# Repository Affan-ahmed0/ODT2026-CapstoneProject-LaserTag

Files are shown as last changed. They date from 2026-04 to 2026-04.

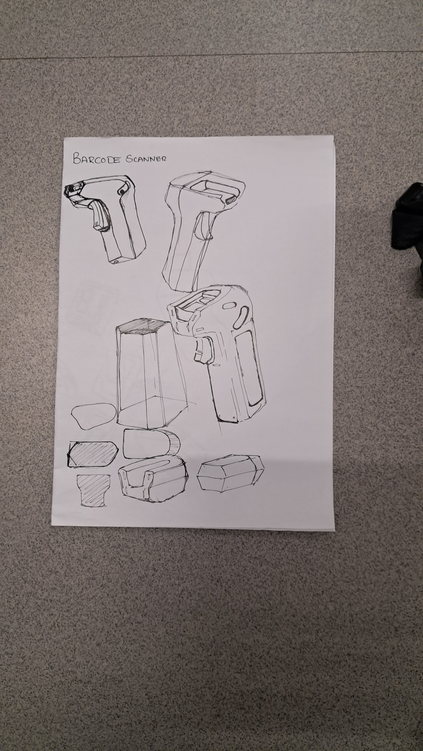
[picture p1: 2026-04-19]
Mechanical Details/Ideation/Final Form.jpg

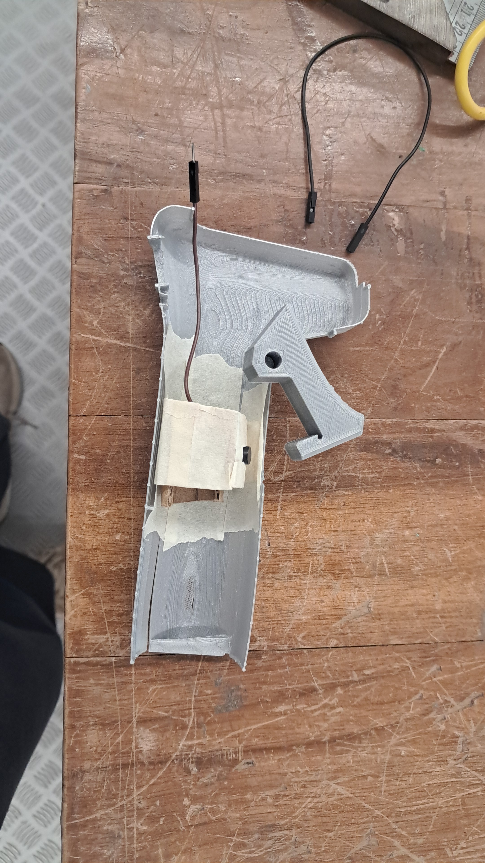
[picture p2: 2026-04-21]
Media/Final/IMG-20260420-WA0010.jpeg

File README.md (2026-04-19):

# **Project Title**

# 🔦⚡Laser Tag⚡🔦

**📌 Project Overview**

A Multiplayer Game of ***Laser Tag***. Where players shoot each other with a gun that shoots lasers to kill the other player. It makes use of the **ESP NOW** Protocol to make a Peer-to-peer architecture, making a gaming platform between that runs between the network of Gun Modules. 

The gun uses IR signals as the communication between the devices when one player is hit. We align the IR Emitter with the Laser module to ensure the visual point of impact (through the Laser) and the digital signal area is aligned. 

**📂 Repository Structure**

1. Electronics Details

2. Mechanical Details

3. Software Details

4. Project Documents

5. Media

**⚙️ How to Navigate This Repository**

Electronics Details → Circuit, components justification

Mechanical Details → Sketches, CAD, and fabrication

Software Details → Code, logic, and implementation

Project Documents → Design thinking, planning, testing

Media → Weekly progress and final output

**👥 Team Members**  

Anushka Kulkarni  

Affan Ahmed

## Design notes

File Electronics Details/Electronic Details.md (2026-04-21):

# Components Used:

**Laser Dot Diode Module:** Acts as visual aid for player to know where they are shooting  

**ESP32:** Used for computing the signals, giving outputs and Wireless communication between ESP32's  

**OLED Display:** Displays information to the Player.  

**Active Buzzer:** Gives audible feedback to the player when hit registered and game ends.  

**3 Stage Slider Switch:** Controls the power to the ESP32  

**Push Button (Trigger):** Fires Laser and IR Emmiter when pressed  

**Battery:** Powers the ESP32

# Components used & Purpose

### Project Components Overview

| Component | Purpose | Justification of Use |
| :--- | :--- | :--- |
| **ESP32 Microcontroller** | Central processing and logic unit. | Processing of signals from sensors and built-in Wi-Fi/Bluetooth for future scoring sync. |
| **Laser Dot Diode (650nm)** | Visual aiming reference. | Provides a clear, visible point of impact for the player without interfering with the IR data stream. |
| **0.96" OLED Display [PIN 21 (SLC) PIN 21 (SDA)]** | Real-time Head-Up Display (HUD). | Provides essential game telemetry (health, ammo, team) in a compact, low-power I2C form factor. |
| **Active Buzzer** | Audio feedback system. | Low-latency audible alerts for "hits" and "firing," essential for situational awareness during play. |
| **3-Stage Slide Switch** | Power and state control. | Switches between Connecting mode to connect between the ESP's in a room and Play mode |
| **Push Button (Trigger)** | Input for firing action. | Provides tactile feedback for the user and give input to the ESP32 |
| **4x AA Battery Pack** | Portable power supply. | Readily available and provides a stable 6V input to the ESP32’s voltage regulator for long-duration play. |

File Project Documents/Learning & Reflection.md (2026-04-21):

## 📝 Project Reflection

This project served as an intensive exploration into the physical and technical constraints of embedded systems. Moving from a conceptual schematic to a handheld, 17cm prototype required navigating a series of cascading engineering challenges. The core of the difficulty lay in the spatial reconciliation between the electronic architecture and the mechanical housing.

The initial planning phase was rigorous, involving detailed CAD modeling in Fusion 360 to ensure the ESP32, OLED, and battery pack would physically coexist within the shell. However, the transition to physical assembly revealed the true complexity of the design. The system relied on an overwhelming number of discrete connections, including I2C lines for the HUD, signal lines for the laser and IR emitter, and the high-speed sampling wire for the raw IR receiver. Each component required precise routing through the narrow internal chassis.

Minor issues with soldering joints and wire fatigue necessitated constant continuity checking, as even a single loose ground would compromise the NEC protocol’s timing. Despite exhaustive planning to join the internal mounting plates with the outer shell, the sheer volume of 22AWG wiring eventually exceeded the internal volume of the 3D-printed gun casing. This density of connections ultimately led to the failure of integrating the circuit inside the gun shell. This struggle highlighted a vital lesson in product design: the "logical" space on a circuit board and the "physical" volume of a housing are two vastly different realities that demand significant margin for error.

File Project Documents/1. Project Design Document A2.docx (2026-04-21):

# Project Design Document

### 1. Design Intent

- The Experience: A high-precision, "sniper-style" competitive game. Unlike commercial IR laser tag that "sprays" light, this is about steady hands and accurate aiming. It creates a high-stakes, "one-shot-matters" atmosphere.
- The Audience: DIY makers, hobbyists, or friends looking for a low-cost, high-tech backyard game.
- The Problem: Professional laser tag equipment is expensive and often relies on "invisible" beams. This project uses visible lasers for immediate feedback and utilizes common, affordable components (LDRs/OLEDs) to make high-tech gaming accessible.

### 2. Inspiration & References

- How Real Laser Tag Works (https://www.youtube.com/watch?v=piLtAyrR_mE)

### 3. User Journey

1. The Start: The player dons the helmet and grips the gun. They flip a toggle switch. The OLED screen splashes a "SYSTEM READY" logo, the neopixel and settles on "LIVES: 03," strip turns on.
2. The Hunt: The user creeps through a low-light environment. They see their opponent and squeeze the Trigger. A red beam streaks across the room.
3. The Interaction: The player's beam hits one of the LDR sensors on the opponent's helmet.
4. The Response: * Opponent Side: Their helmet MCU detects the sudden drop in LDR resistance. The OLED flashes "HIT!" and the life count drops to "02." The Neopixel strip flashes red for 3 seconds to indicate a hit.
  - Attacker Side: The attacker sees the opponent's flash, confirming a successful strike.
5. Cooldown: There is a cooldown of 3 seconds after every 15 shots. There is also a 3-second invulnerable state for player who has just been shot.
6. The End: Once a player's OLED hits "00," the screen displays "GAME OVER – DEFEATED."

### 4. Success Criteria

- Functional: Hit detection must occur in <100ms to feel "real-time." The laser must stay active only as long as the trigger is held (or for a set pulse duration).
- User Experience: The OLED must be high-contrast enough to read at a glance while moving. The helmet must be light enough to be comfortable for 15 minutes of play.
- Reliability: The system must distinguish between a laser hit and ambient room light (achieved through software thresholding).

### 5. System Overview

The system is a Distributed Wearable Network. Each "Player Unit" is a closed loop.

- The Brain (MCU): An Arduino Nano or ESP32 mounted on the helmet.
- The Peripheral (Gun): Connected via a "leash" wire, containing the laser diode and the trigger button.
- The Sensory Array (Helmet): 3–4 LDRs wired in parallel or to individual analog pins to provide 360° detection coverage.
- The Interface (OLED): A 0.96" I2C screen providing health and ammo status.

### 6. High-Level Block Diagram

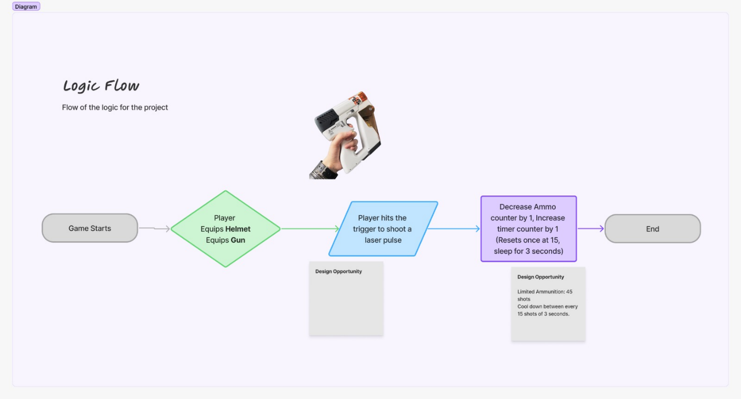
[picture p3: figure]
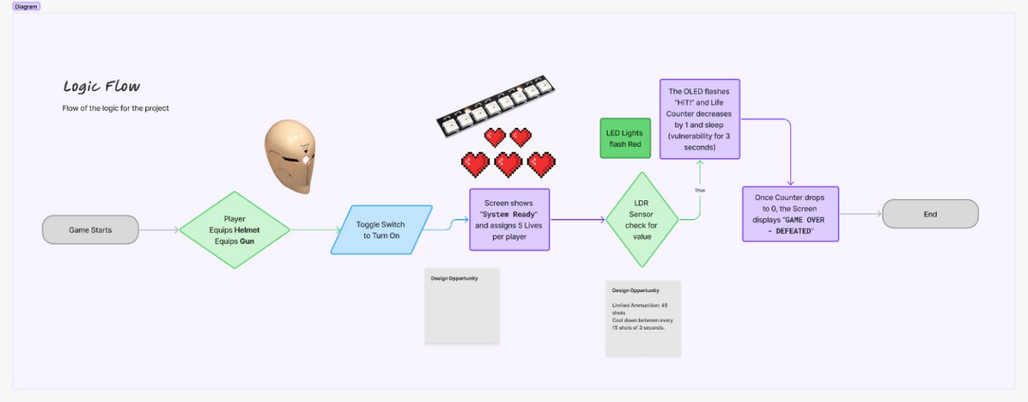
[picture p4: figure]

### 7. Input / Output Mapping

Input | Process | Output
Trigger Button (Digital Input) | Check if player has "lives" left. If yes, send power to Laser Diode. | Laser Beam (Red light emission)
LDR Sensor (Analog Input) | Compare light level to a pre-set "Threshold." If change is >40%, trigger "Hit Logic." | OLED Update (Lives -1)
LDR Sensor (Analog Input) | If "Hit Logic" is active, start a 2-second "Invincibility Timer." | Status LED (Red flashing)
Software Timer | Monitor time since last shot to prevent "Machine Gun" spamming. | OLED Animation ("Reloading...")

### 8. Sketches & Concepts

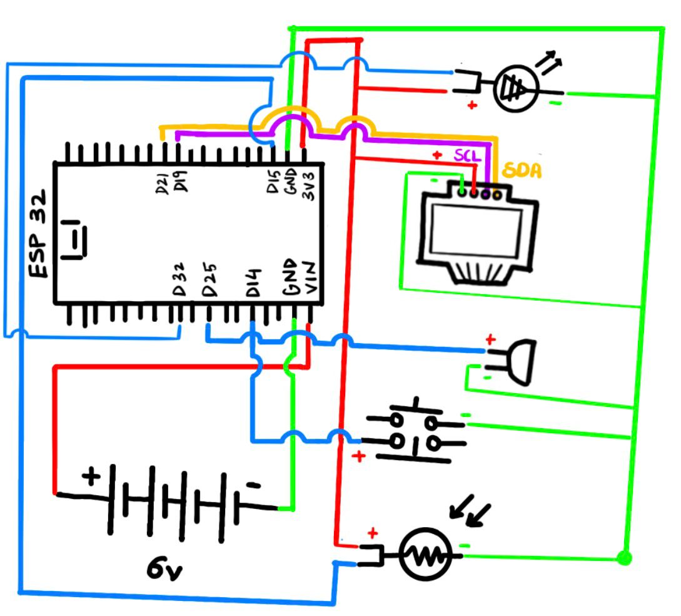
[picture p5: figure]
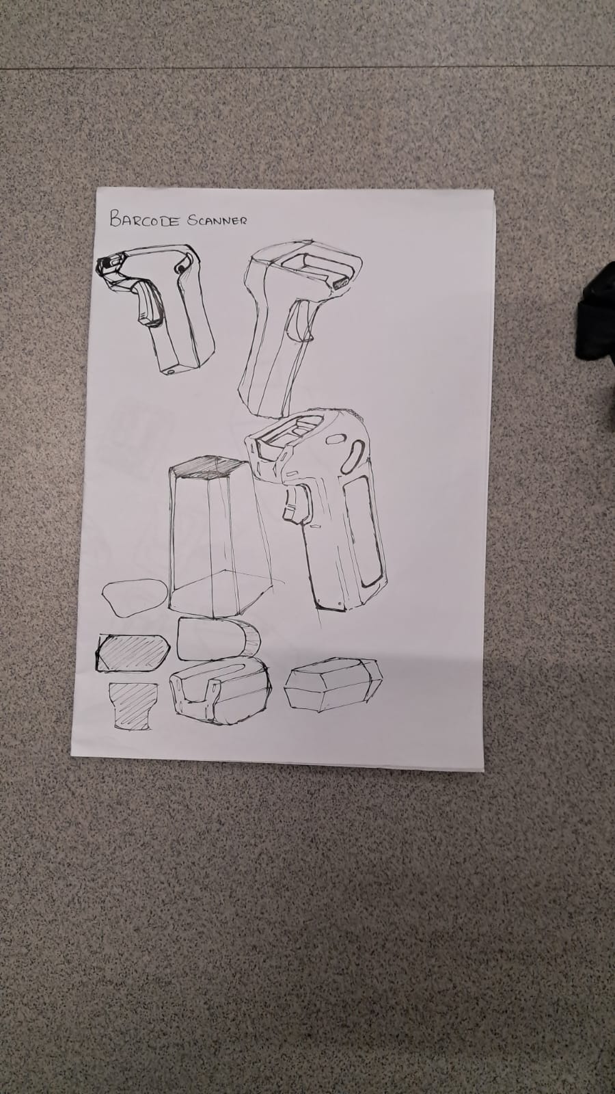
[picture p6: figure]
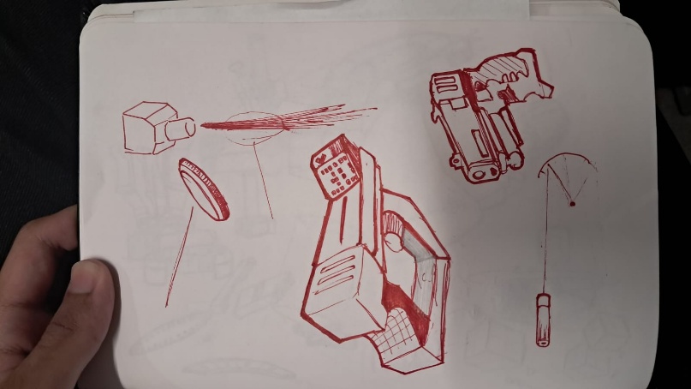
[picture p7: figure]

### 9. Final System Architecture (Labelled)

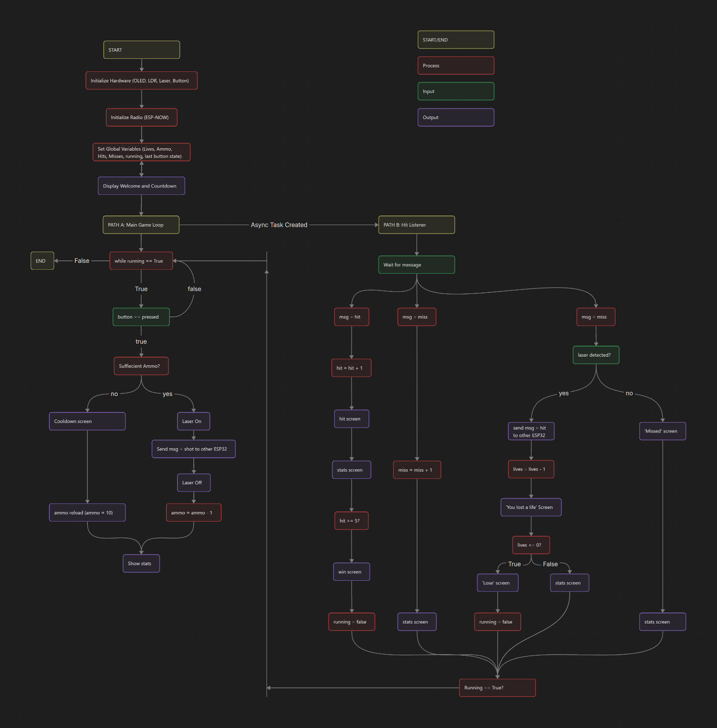
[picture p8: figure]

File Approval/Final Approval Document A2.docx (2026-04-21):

ODT Summative 2

Idea Brief:

1. Project Overview

Photon Strike is a wearable electronic game consisting of a hand-held laser emitter (The Gun) and a head-mounted receiver (The Helmet). The goal is to "tag" opponents by hitting their helmet sensors with a laser beam. Each helmet tracks its own health or hit count in real-time, displaying the data on an integrated OLED screen.

2. Hardware Architecture

The Gun (Emitter)

- Laser Pointer
- Trigger
- Feedback: A buzzer for "pew-pew" sounds

The Helmet (Receiver)

- ESP32: To process sensor data and drive the display.
- LDR Sensor
- Display: OLED Screen (128x64) mounted on the brim or side to show "Lives Remaining" or "Hit Count."
- Indicator: A bright LED that flashes when the player is hit.

3. Core Game Mechanics

1. The Shot: When the trigger is pulled, the laser emits a brief pulse.
2. The Detection: The LDRs on the helmet constantly monitor ambient light levels. When a laser hits an LDR, the resistance drops sharply and suddenly.
3. The Logic: The microcontroller detects this "voltage spike." To prevent sunlight or room lights from triggering a hit, the code must look for a specific threshold of change over a very short duration.
4. Feedback Loop: The OLED updates the score (e.g., "HITS: 04").
  - The helmet buzzer sounds for 1 second.
  - The helmet goes into a brief "invincibility window" (2 seconds) to prevent multi-hit spamming.

Basic Idea Sketch

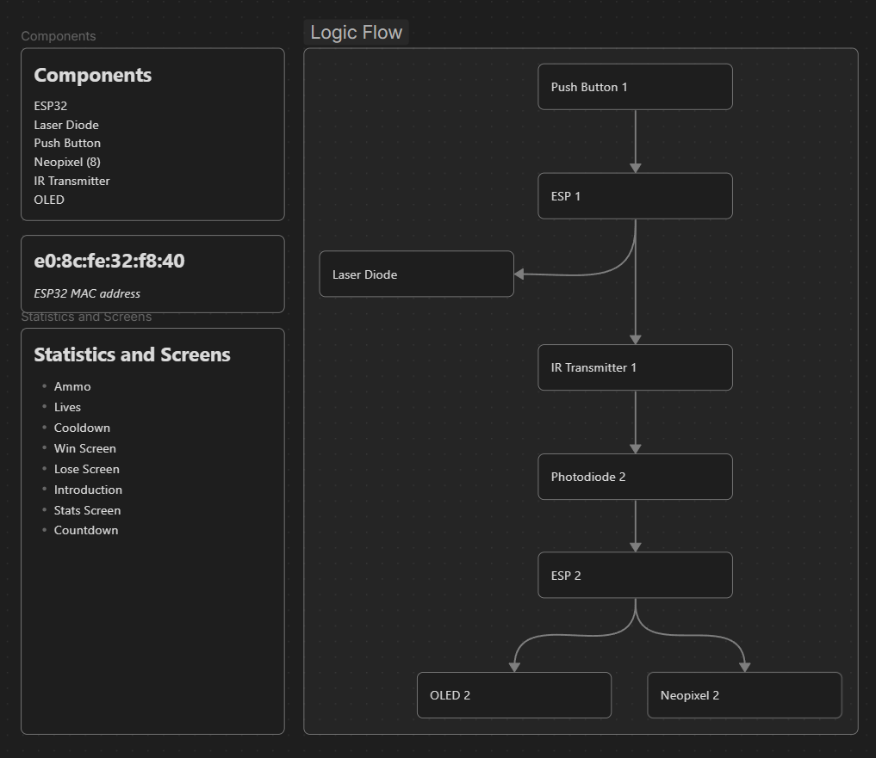
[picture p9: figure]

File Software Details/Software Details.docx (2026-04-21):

# Software Documentation

### 1. Software Overview

What does the software do?

- The software manages a real-time, wireless laser tag duel system for two players. It coordinates the hardware components (Laser, LDR, Button, and OLED Display) and handles peer-to-peer communication between two ESP32 microcontrollers using the ESP-NOW protocol.

Key features include:

- Asynchronous Dual-Track Processing: The software utilizes asyncio to simultaneously monitor the trigger/laser firing logic (Attacker track) and an background radio listener (Victim track).
- Response-Confirmation Handshake: Unlike simple one-way infrared systems, this software uses a "handshake" protocol. When a shot is fired, the attacker notifies the victim via radio; the victim immediately checks their sensor and broadcasts a confirmation ("Hit" or "Miss") back to the attacker to update scores in real-time.
- State Management: The system tracks and displays live game statistics, including health (lives), ammunition, successful hits, and misses, while enforcing game rules like firing cooldowns and win/loss conditions.

Platforms Used

- MicroPython (v1.20+): The primary programming language used for the firmware, chosen for its efficient handling of hardware-level interrupts and high-level asynchronous programming.
- asyncio Library: Used to manage non-blocking tasks, ensuring the gun remains responsive to being hit while the player is busy firing or navigating menus.
- aioespnow: A specialized MicroPython wrapper for ESP-NOW, a connectionless Wi-Fi communication protocol that provides low-latency, long-range data transmission between the devices.
- SSD1306 OLED Driver: A frame-buffer based driver used to render the graphical user interface (GUI) and real-time statistics on the I2C display.
- Thonny IDE: Used for script development, debugging, and flashing the modular file system (main.py, comms.py, screen.py) to the ESP32 units.

### 2. System Logic

1. Game Initialization
- Boot: The ESP32 initializes the Wi-Fi radio (ESP-NOW), I2C Display, and GPIO pins (Laser, Button, Sensor).
- Setup: The screen displays a welcome sequence and countdown while the background "Listener" task starts.
- Standby: The system enters a loop, waiting for either a trigger pull (Attacker) or a radio signal (Victim).
2. The Attacker Flow (Shooting)
- Trigger: User presses the physical button.
- Action: If ammo is available, the ESP32 turns on the Laser and simultaneously broadcasts a "Shot" signal via ESP-NOW.
- Wait: The Attacker pauses for the victim’s response (handled by the background listener).
- Result:
- If a "Hit" signal is received back: The score (hits) increases and a "Victory" animation plays.
- If a "Miss" signal is received back: The "Misses" count increases.
3. The Victim Flow (Being Shot At)
  a. Radio Catch: The background listener receives a "Shot" signal from the opponent.
  b. Sensor Check: The ESP32 immediately reads the LDR (Light Dependent Resistor) value.
4. Detection:
  a. If Laser detected: The ESP32 subtracts a life, displays a "Hit" animation, and sends a "Hit" confirmation back to the attacker.
  b. If Laser NOT detected: The ESP32 sends a "Miss" confirmation back to the attacker.
5. End of Game
  - Victory/Defeat: The system constantly checks if lives == 0 or hits == 5.
  - Kill-Switch: Once a condition is met, the global running flag is set to False.
  - Termination: Both the main loop and background listener stop, and the final "Win" or "Lose" screen is displayed.

### 3. Flowchart


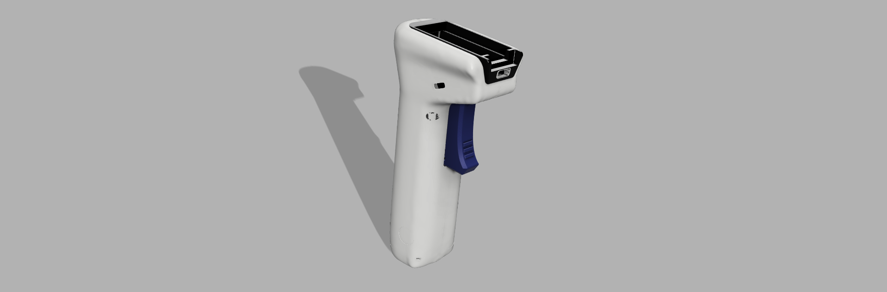
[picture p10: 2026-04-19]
Mechanical Details/CAD Files/LaserGun v23.png

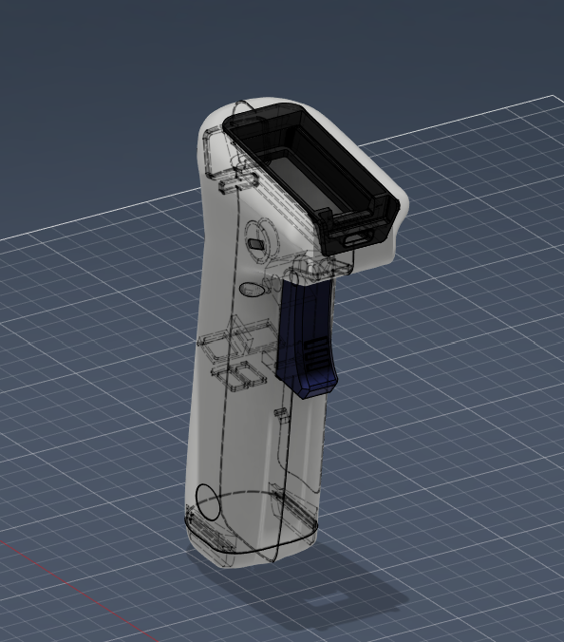
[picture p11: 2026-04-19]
Media/Week2/3-4th view.png

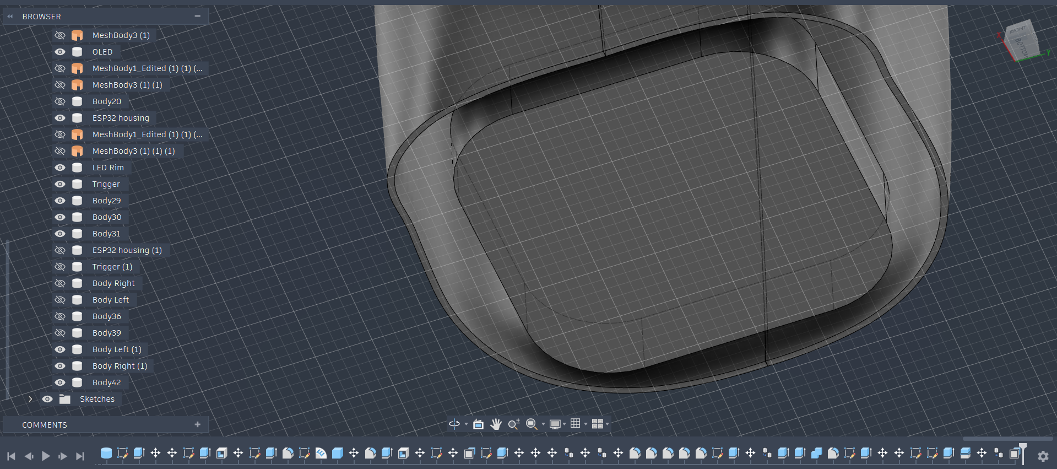
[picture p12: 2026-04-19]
Media/Week2/Bottom View.png

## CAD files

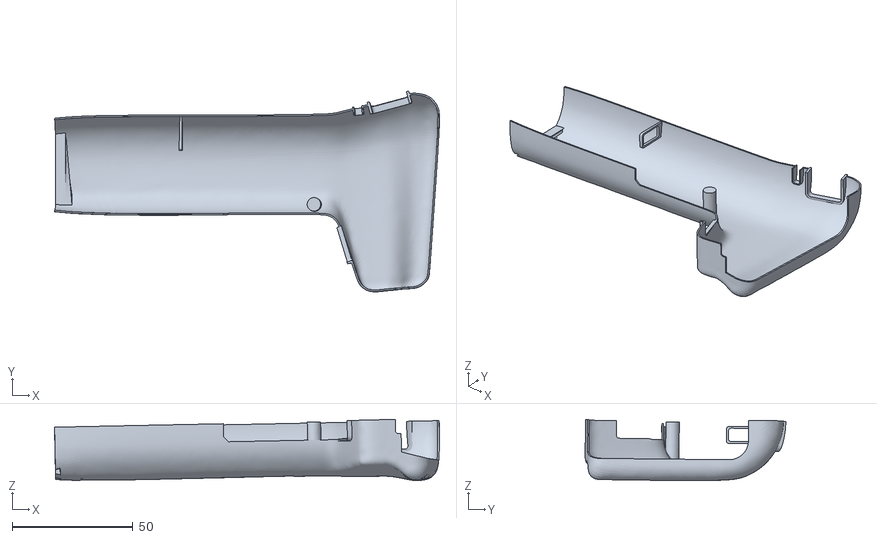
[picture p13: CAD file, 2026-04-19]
Mechanical Details/CAD Files/LaserGunBase.stl_1.stl
159.2 x 83.0 x 25.3

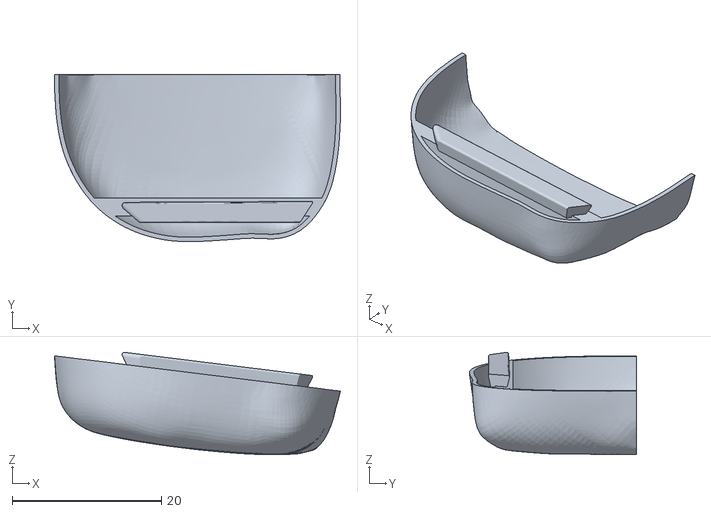
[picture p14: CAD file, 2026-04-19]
Mechanical Details/CAD Files/LaserGunBottom.stl_2.stl
38.4 x 22.5 x 13.7

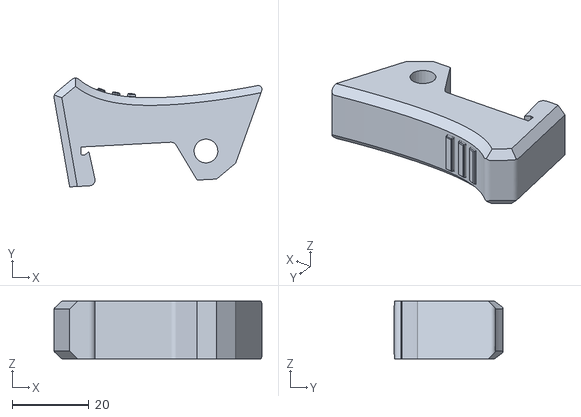
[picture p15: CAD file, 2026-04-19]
Mechanical Details/CAD Files/LaserGun.stl_4.stl
54.2 x 28.3 x 15.0

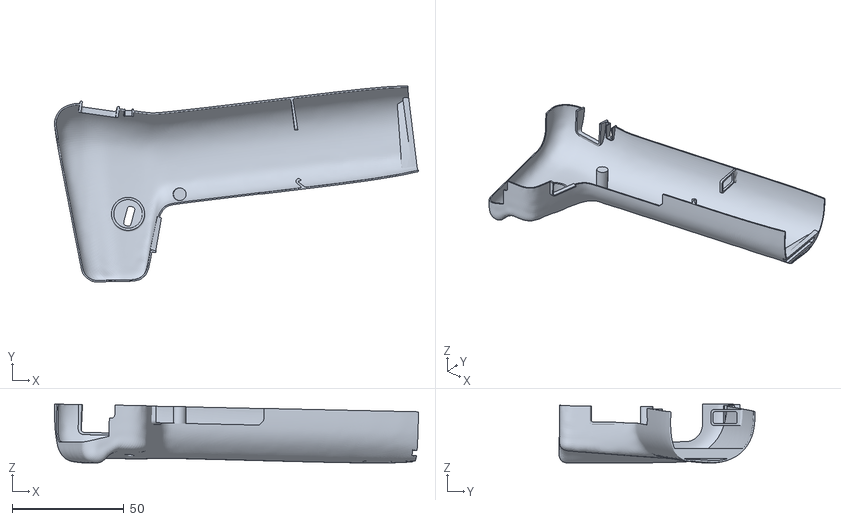
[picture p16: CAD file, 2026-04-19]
Mechanical Details/CAD Files/LaserGunBase.stl_2.stl
162.9 x 87.8 x 26.4

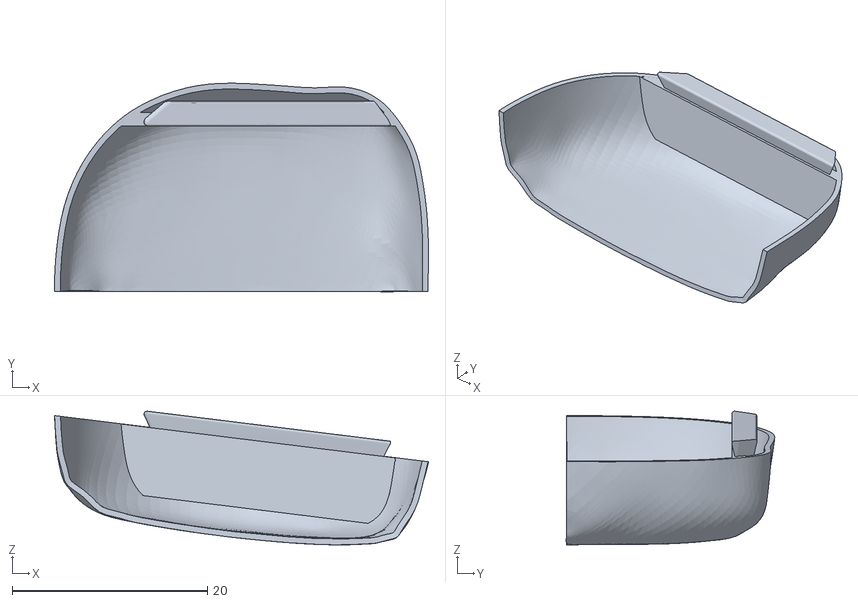
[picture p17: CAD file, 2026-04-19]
Mechanical Details/CAD Files/LaserGunBottom.stl_1.stl
38.3 x 21.4 x 13.7

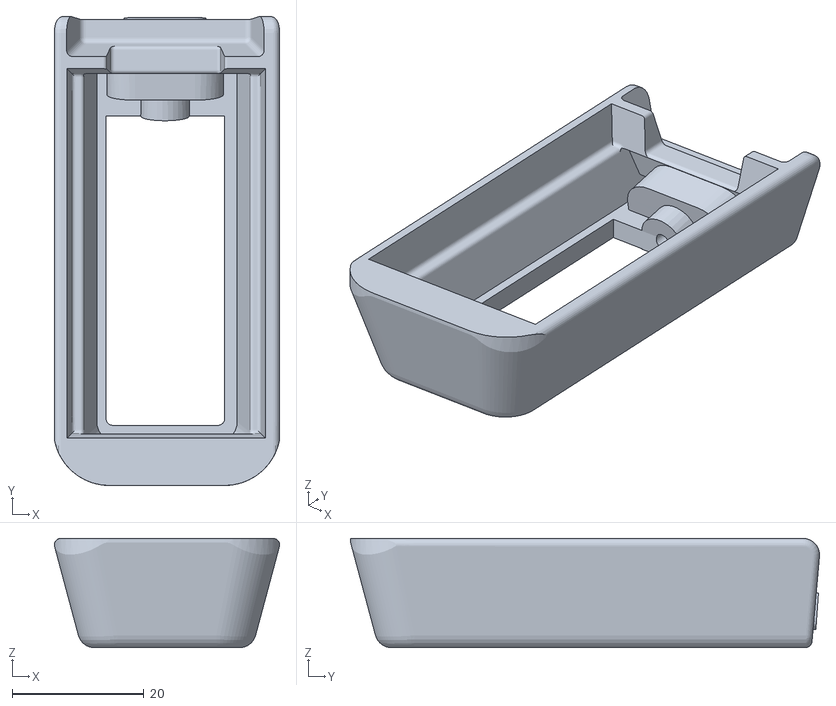
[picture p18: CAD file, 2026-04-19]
Mechanical Details/CAD Files/LaserGun.stl_7.stl
34.2 x 71.2 x 16.6

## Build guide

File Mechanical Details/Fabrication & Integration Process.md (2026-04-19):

# Material Note:
**Considerations-** Weight of batteries - It is placed at the bottom so that the weight of the gun remains heavy to the user, but it isn't top heavy, making it easy to still swing around when in action
**Sturdiness** (Didnt Work Out) - The shell must be sturdy to take the force of the grip of players running around and shooting.

# Fabrication And Macufacturing:
The shell of the object was 3D Printed to house all the components internally, excluding the IR Reciever. 3D Printing was used to deliver the precision required to place all the components in the preferred position in one cohesive shell. 
It houses the Battery, Buzzer, Slide Switch, OLED and the IR Emmiter.

# Assembly Steps:
-  3D Model the Shell
-  3D Print in 2 halves
-  Join Halves

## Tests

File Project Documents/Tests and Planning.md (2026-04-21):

### Project Planning and Testing Framework

| Phase | Activity | Objectives | Outcome/Status |
| :--- | :--- | :--- | :--- |
| **Initial Planning** | **Mechanical CAD Modeling** | [cite_start]Design a 17cm x 9cm housing in Fusion 360 to contain all electronics[cite: 3, 59, 62]. | Housing designed with integrated mounting plates and an ergonomic handle for a 4x AA battery pack. |
| **Initial Planning** | **System Architecture** | [cite_start]Define the multi-layer logic for detection, control, and feedback using an ESP32[cite: 22, 23, 26]. | Established a decentralized P2P model using MicroPython and the ESP32 NOW protocol for robust data exchange. |
| **Testing** | **Protocol Verification** | Ensure the NEC signal timing (9ms pulse/4.5ms space) is accurate using the RMT peripheral. | Confirmed via logic analysis that the carrier wave remains stable under processor load. |
| **Testing** | **Signal Demodulation** | Test the raw IR receiver's ability to distinguish 38kHz pulses from ambient light.
| **Integration** | **Circuit Dry-Run** |Verify all components (OLED, Buzzer, Laser) function together on a breadboard. | Successfully tested the full feedback loop: trigger press leads to IR transmission and local UI update. |
| **Integration** | **Housing Fitment** | Attempt to integrate the wired circuit into the 3D-printed gun shell. | **Failure:** The overwhelming number of discrete connections exceeded the internal volume of the shell. |
| **Post-Mortem** | **Failure Analysis** | Evaluate why the circuit did not fit despite exhaustive CAD planning. | Identified that 22AWG wiring density and cumulative solder joint volume were not sufficiently accounted for in CAD. |

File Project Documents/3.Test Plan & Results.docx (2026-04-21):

# Test Plan & Results

### 1. Test Plan

Test | Method | Expected Result
Playability, Screen Updates | Playtest | Basic Laser Tag Game on breadboard (more like target practice game at the current scale)

### 2. User Testing

- Users: Friends
- 3 Friends played against each other

### 3. Results

Test | Outcome | Pass/Fail
Playability | Button Issues, Basic flow: Okay | Fail
Screen Updating | Good Flow | Pass

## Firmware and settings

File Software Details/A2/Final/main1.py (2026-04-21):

from machine import Pin, I2C
import machine, ssd1306
import framebuf
import time
import screen
import comms
import asyncio


# HARDWARE INITIALIZARION
lz = Pin(32, Pin.OUT)
ldr = Pin(15, Pin.IN, Pin.PULL_UP)
pb = Pin(14, Pin.IN, Pin.PULL_UP)

# GAME VARIABLES & TRACKING
ammo = 10
lives = 5
hits = 0
misses = 0
last_button_state = 1

running = True

# HIT LISTENER
async def hit_listener():
    global hits, misses, lives, running
    while True:
        msg = await comms.arcv() 
        
        if msg == "hit2":
            hits = hits + 1
            await asyncio.gather(screen.hit(), screen.bzhit())
            await screen.stats(lives, ammo, hits, misses)
            if hits >= 5:
                await asyncio.gather(screen.bzend(), screen.win())
                running = False
                break
            
        elif msg == "miss2":
            misses = misses + 1
            await asyncio.gather(screen.bzmiss(), screen.miss())
            await screen.stats(lives, ammo, hits, misses)
        
        elif msg == "shot2":
            if ldr.value() == 0:
                await comms.asend("hit1")
                lives = lives - 1
                await screen.life(lives)
                if lives <= 0:
                    await asyncio.gather(screen.bzend(), screen.lose())
                    running = False
                    break
                await screen.stats(lives, ammo, hits, misses)
            else:
                await comms.asend("miss1")
                await screen.stats(lives, ammo, hits, misses)
        await asyncio.sleep(0.1)


# SHOOTER (MAIN LOOP)
async def main_game():

    # GAME INITIALIZATION
    global lives, ammo, hits, misses, last_button_state, running
        
    await screen.welcome()
    
    await screen.press()
    
    while pb.value() == 1:       # Gate for the rest of the code
        await asyncio.sleep(0.1)
    
    await screen.getready()
    await screen.countdown()
    asyncio.create_task(hit_listener())
    await screen.stats(lives, ammo, hits, misses)

    while running == True: # ATTACK
        click = pb.value()
        if click == 0  and last_button_state == 1:
            
            # SUFFICIENT AMMO
            if ammo >= 1:
                lz.on()
                await asyncio.sleep(0.3)
                await comms.asend("shot1")
                lz.off()
                ammo = ammo - 1

            # INSUFFICIENT AMMO
            elif ammo <= 0:
                await screen.cooldown()
                ammo = 10
                await asyncio.gather(screen.bzcool(), screen.countdown())
                
            await screen.stats(lives, ammo, hits, misses)

        last_button_state = click
        await asyncio.sleep(0.05)
        
asyncio.run(main_game())

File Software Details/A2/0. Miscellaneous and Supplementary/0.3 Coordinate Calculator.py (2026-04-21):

def get_center_coords(text, screen_w=128, screen_h=64):

    text_w = len(text) * 8
    text_h = 8
    
    x = (screen_w - text_w) // 2
    y = (screen_h - text_h) // 2
    return x, y

while True:
    my_text = input("Enter your word(s): ")
    start_x, start_y = get_center_coords(my_text)
    print(my_text, start_x, start_y)
